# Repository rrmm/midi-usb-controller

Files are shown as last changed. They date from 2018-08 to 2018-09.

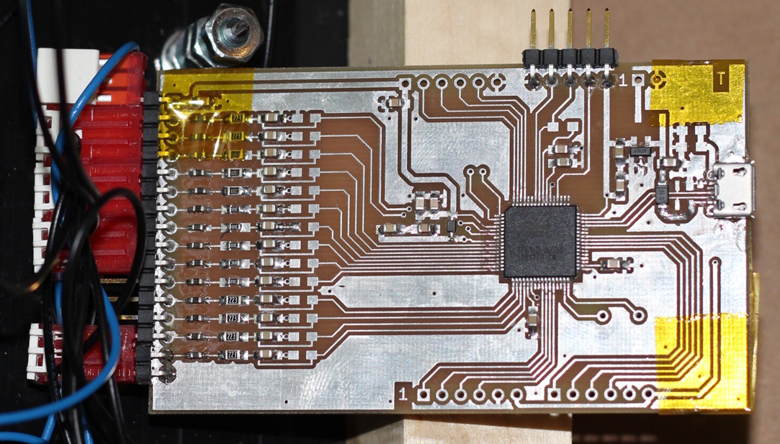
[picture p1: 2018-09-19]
prototype-pcb.jpg

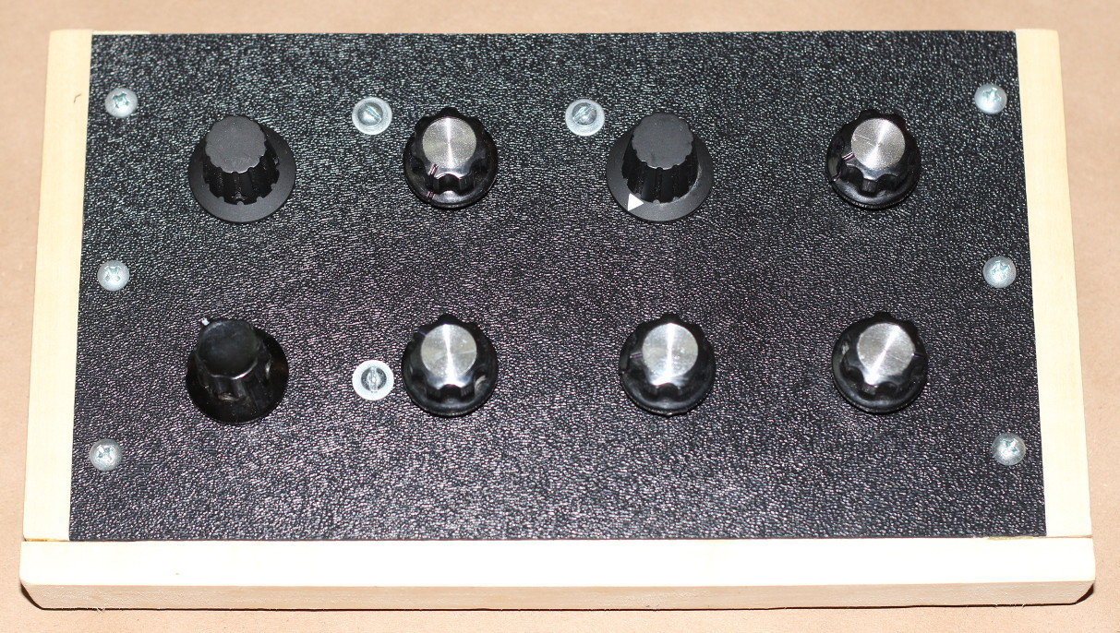
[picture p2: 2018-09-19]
prototype-front.jpg

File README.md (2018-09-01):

# midi-usb-controller

All project files Copyright 2018 RM 
CC BY-SA license with the conditions of the ASF license 

Custom PCB and firmware to implement a MIDI controller board 
- based on Atmel/Microchip ATSAMD21J18A-AU microcontroller
- hardware/gerber contains files necessary to have PCB's manufactured
- USB MIDI device class means no custom drivers are required for WIN or Linux
- bus-powered requires only a single USB micro cable

NOTES
-----
- Controls used were 10K linear potentiometers
- the controls are sampled periodically (~5ms)
- when control changes are detected, they are entered into a FIFO queue
- USB is handled via interrupts and the start of frame (SOF) interrupt checks the queue and transmits 
any events found there
- based on ATMEL STUDIO CDC project with only a single change to the core code to expose one function 
(udd_ep_job_t* udd_ep_get_job(udd_ep_id_t ep))
- several serial ports and crystals are supported by the board to make it more flexible although they are not necessary for 
normal USB operation
- the 100nF capacitors in the low-pass filter of each control input were not used/necessary
- built prototype uses some 10K resistors and some 22K resistors in the low-pass filters without noticible effects
- src/main.c contains the initialization and controller sampling.  It also defines which control is treated as a pitchbend wheel
- src/midi dir contains the actual device implementation and USB config descriptors
- src/config/  contains some important definitions in the clock and usb files (including the midi device descriptor strings)

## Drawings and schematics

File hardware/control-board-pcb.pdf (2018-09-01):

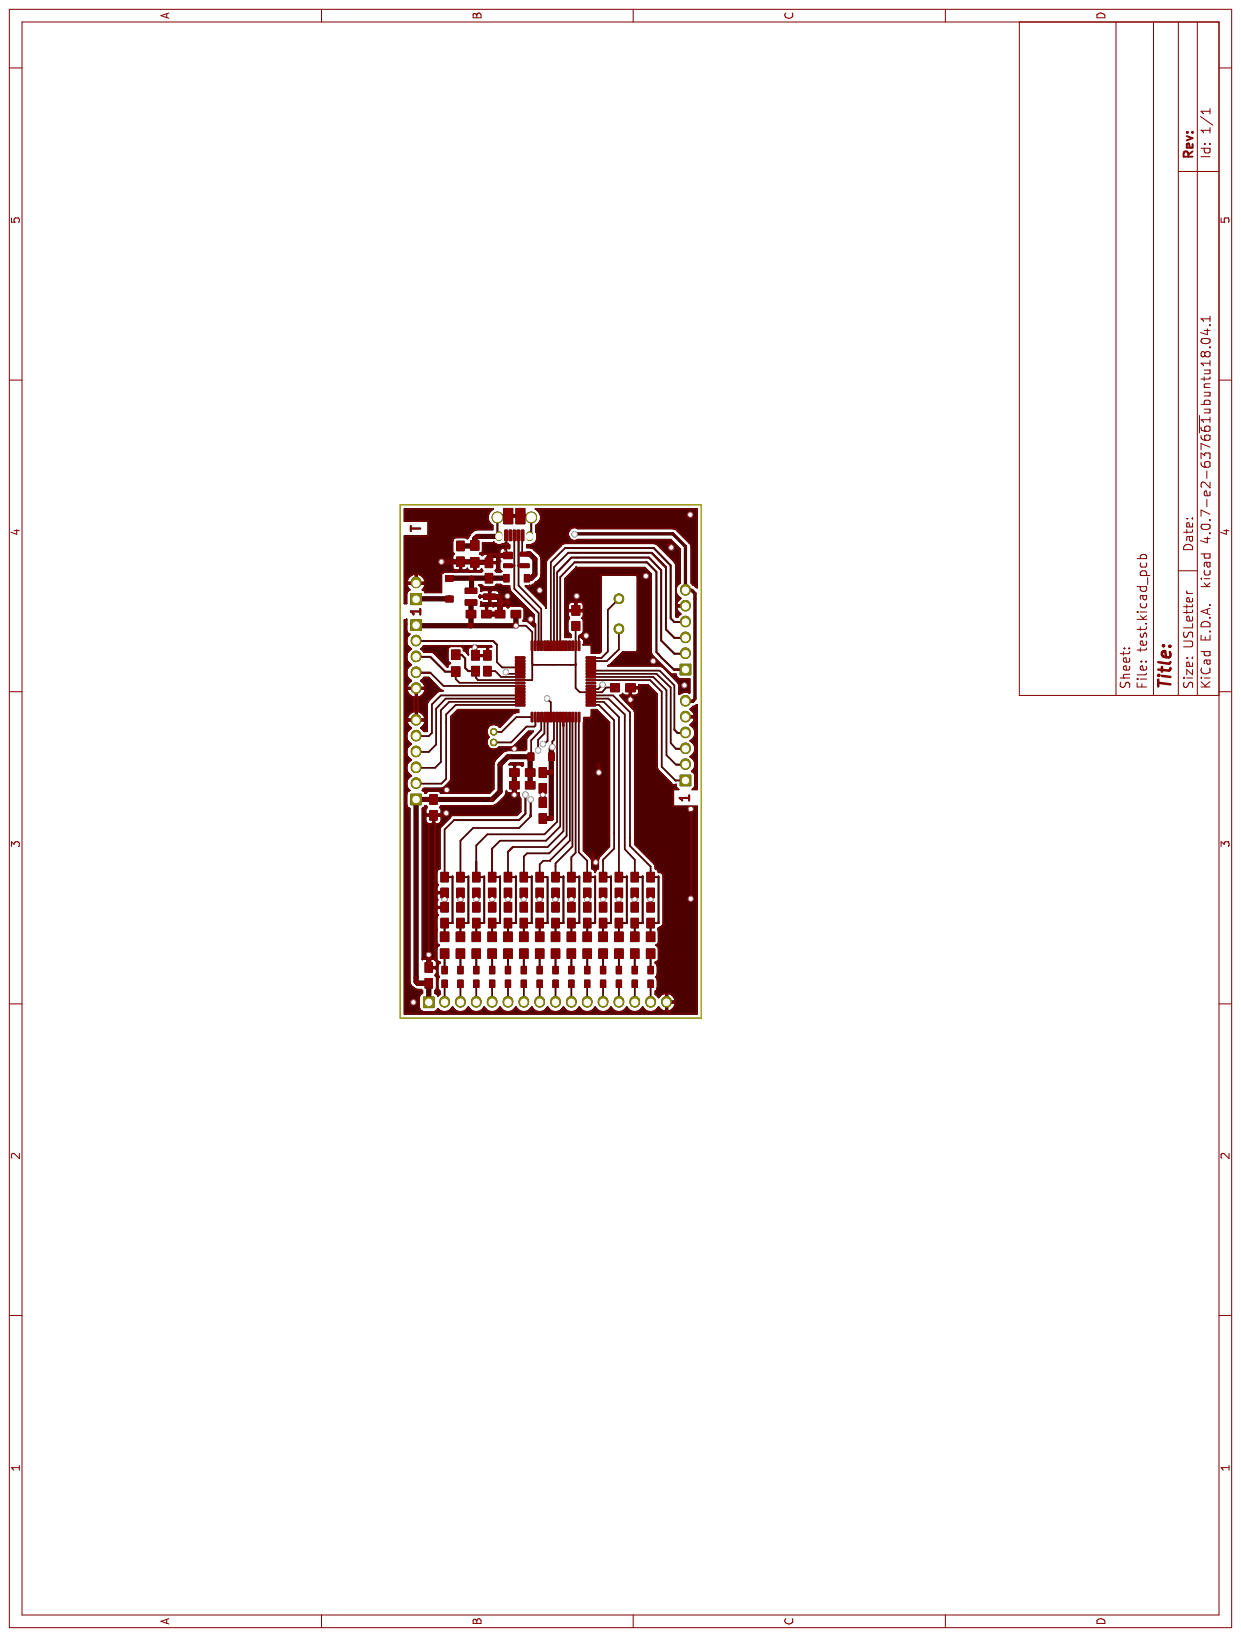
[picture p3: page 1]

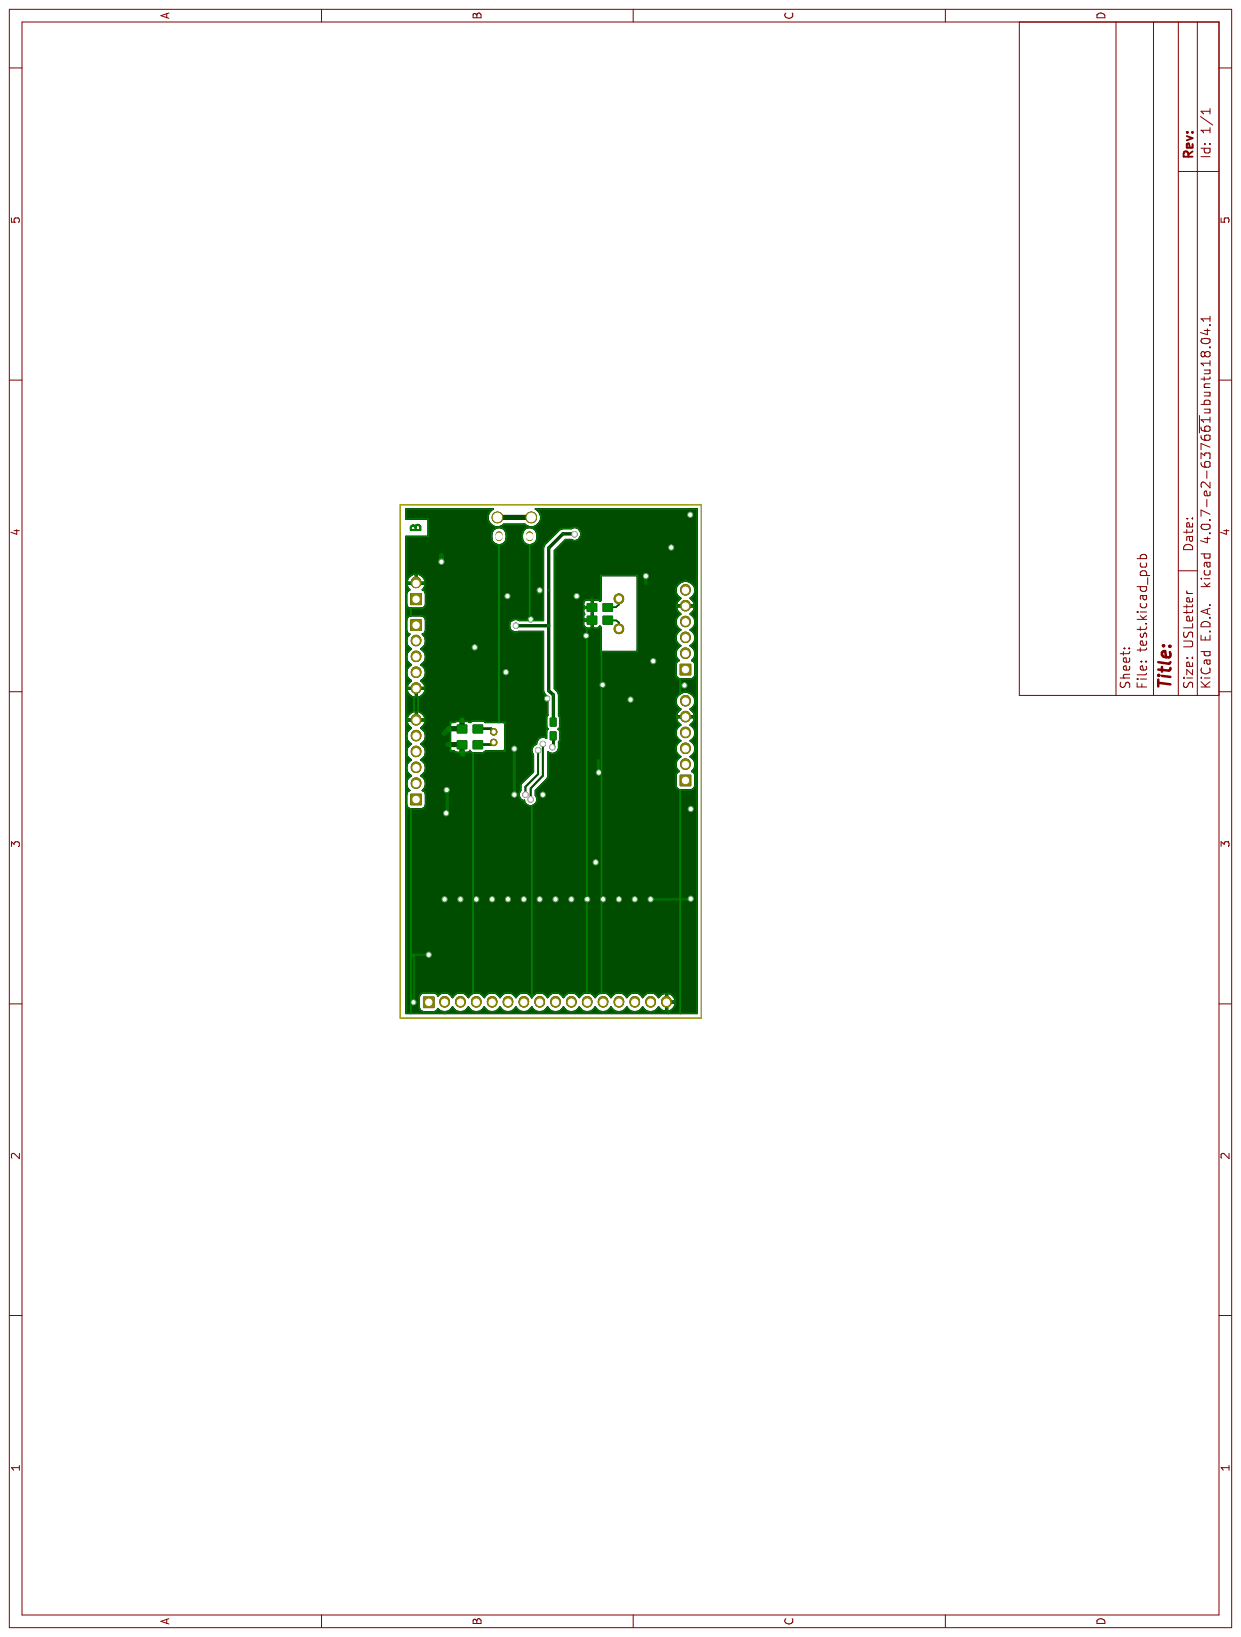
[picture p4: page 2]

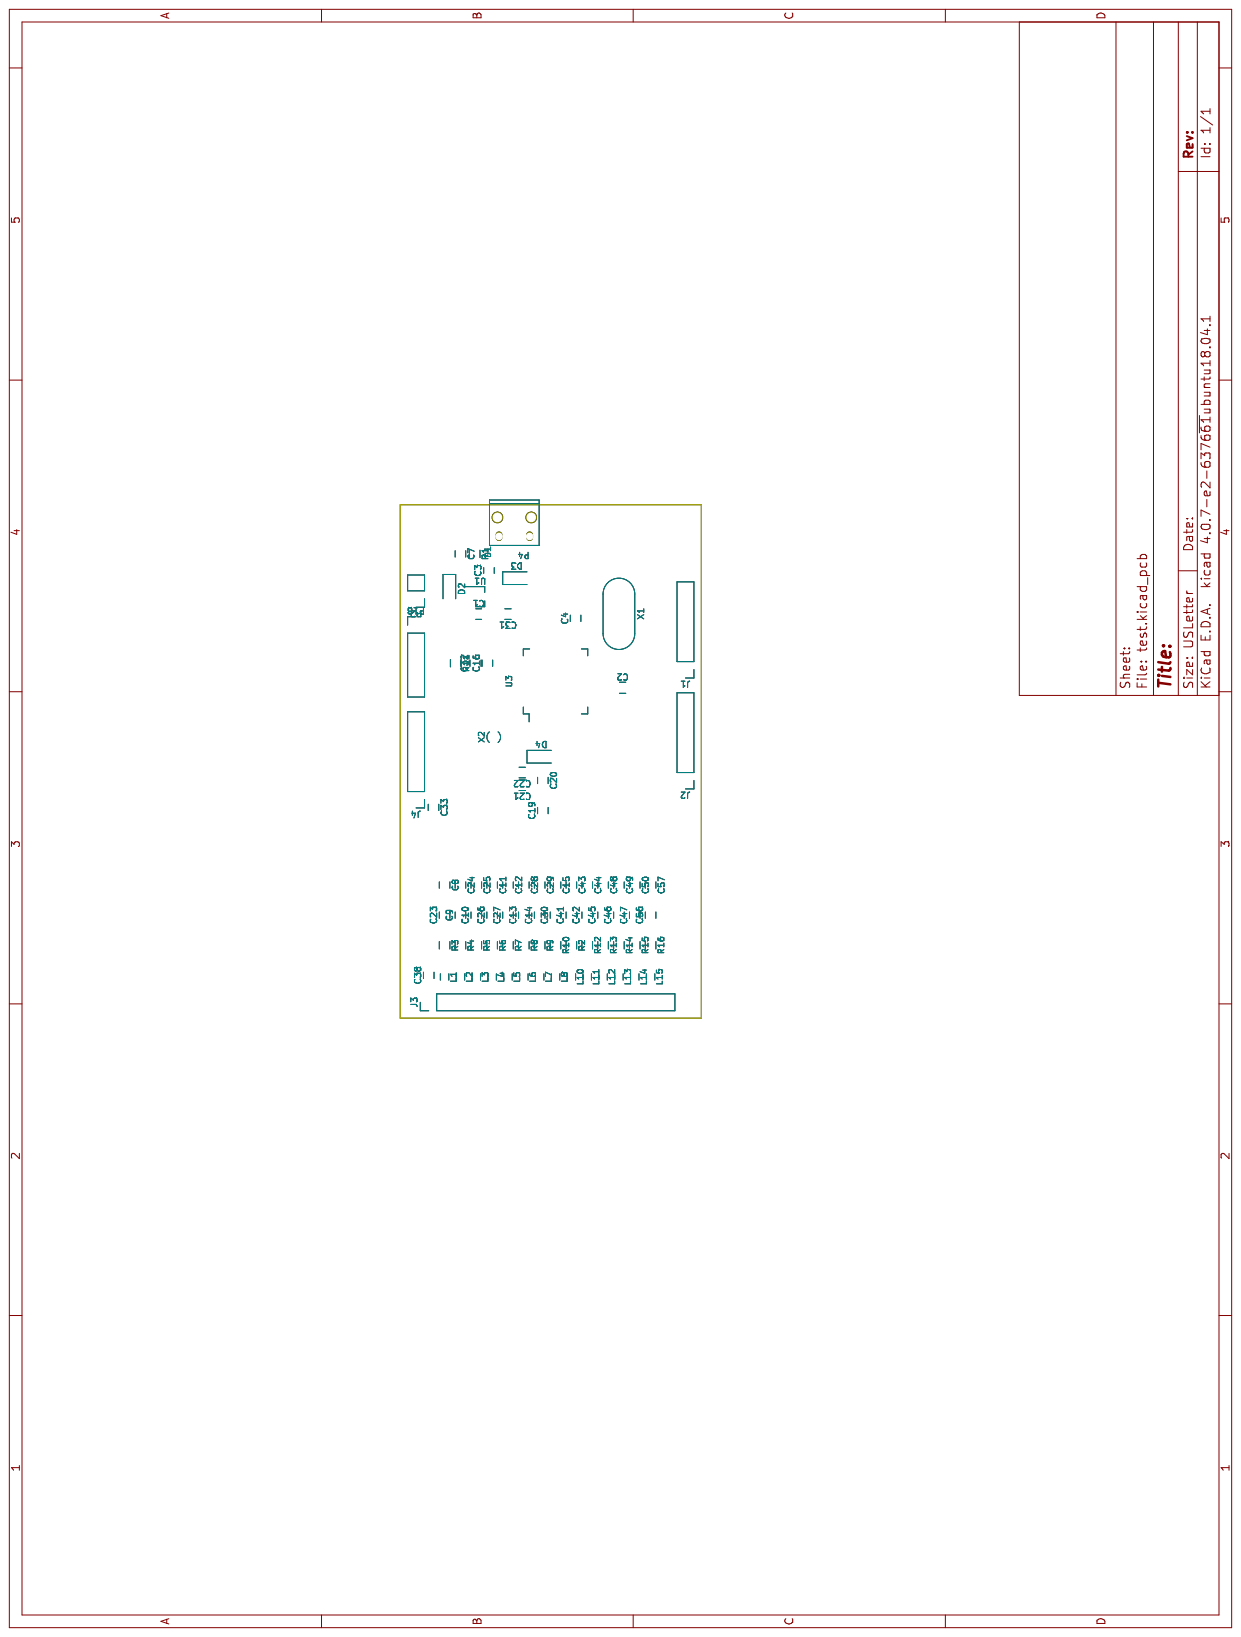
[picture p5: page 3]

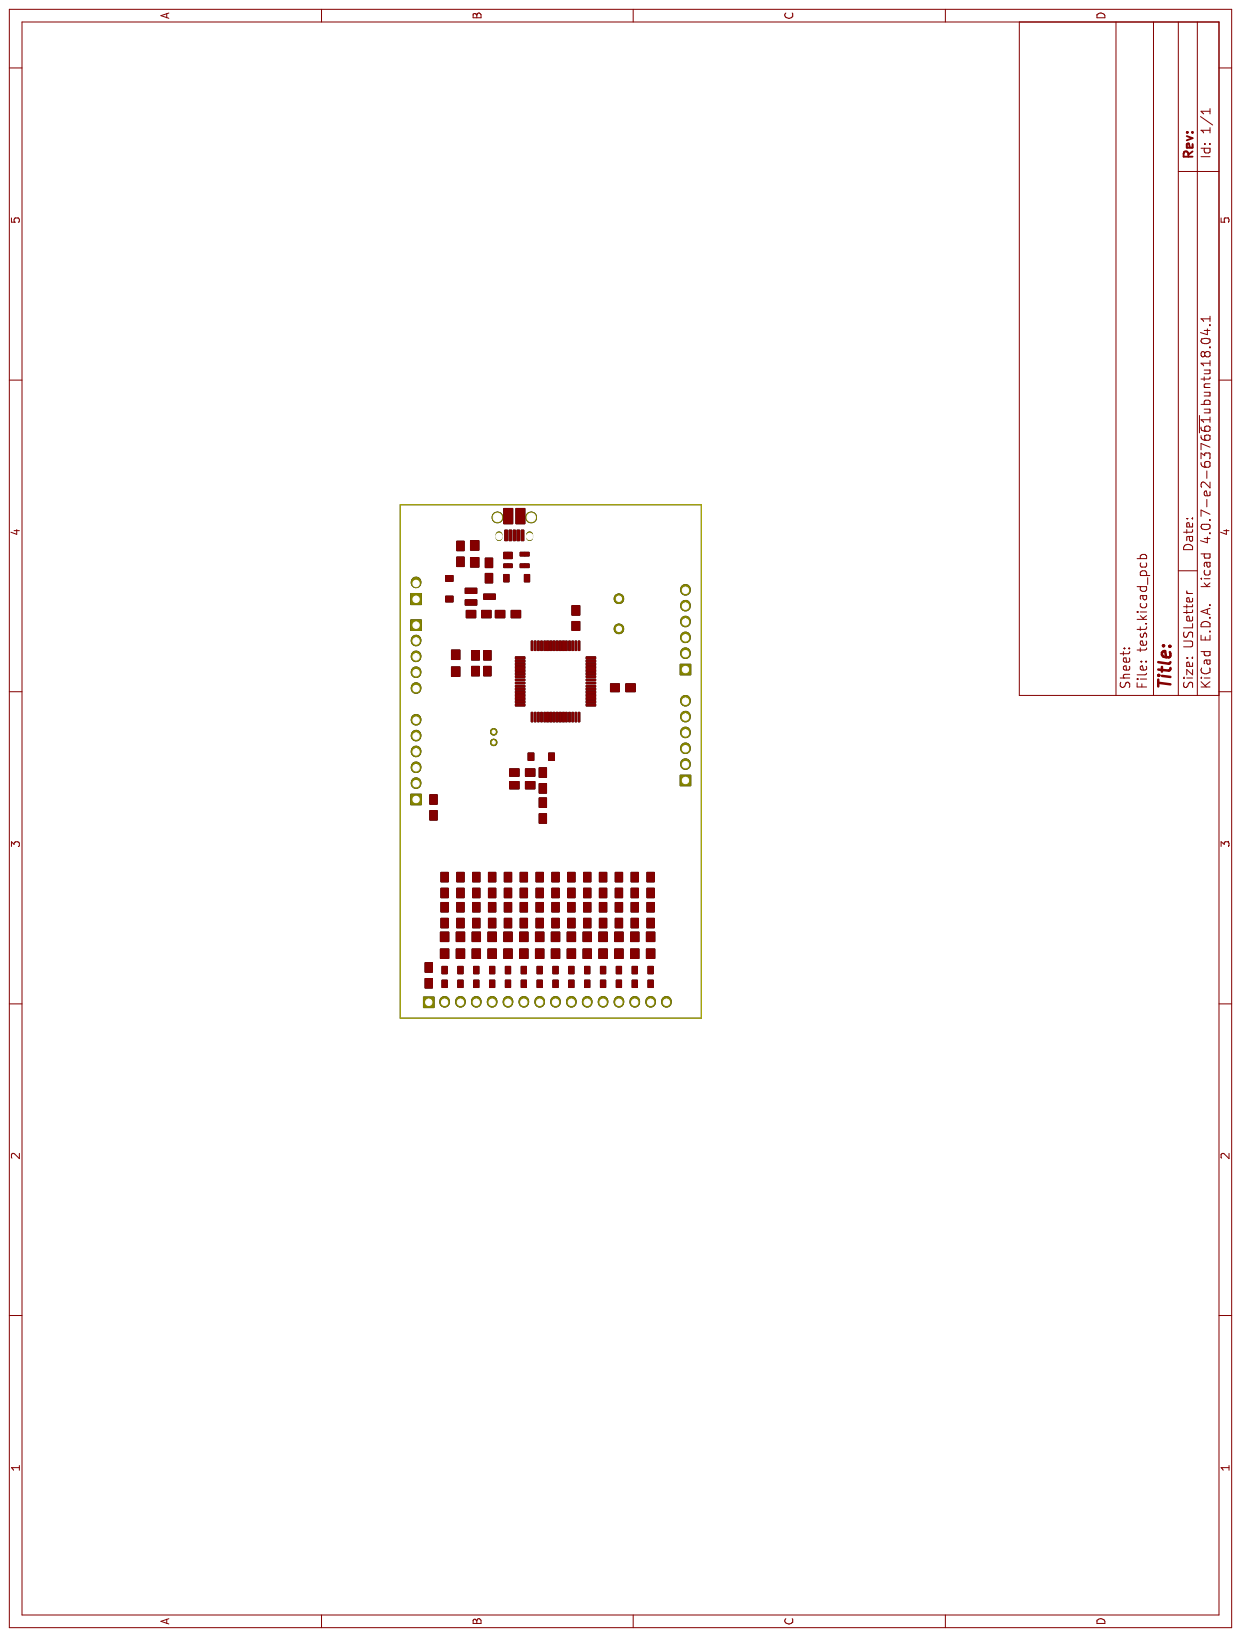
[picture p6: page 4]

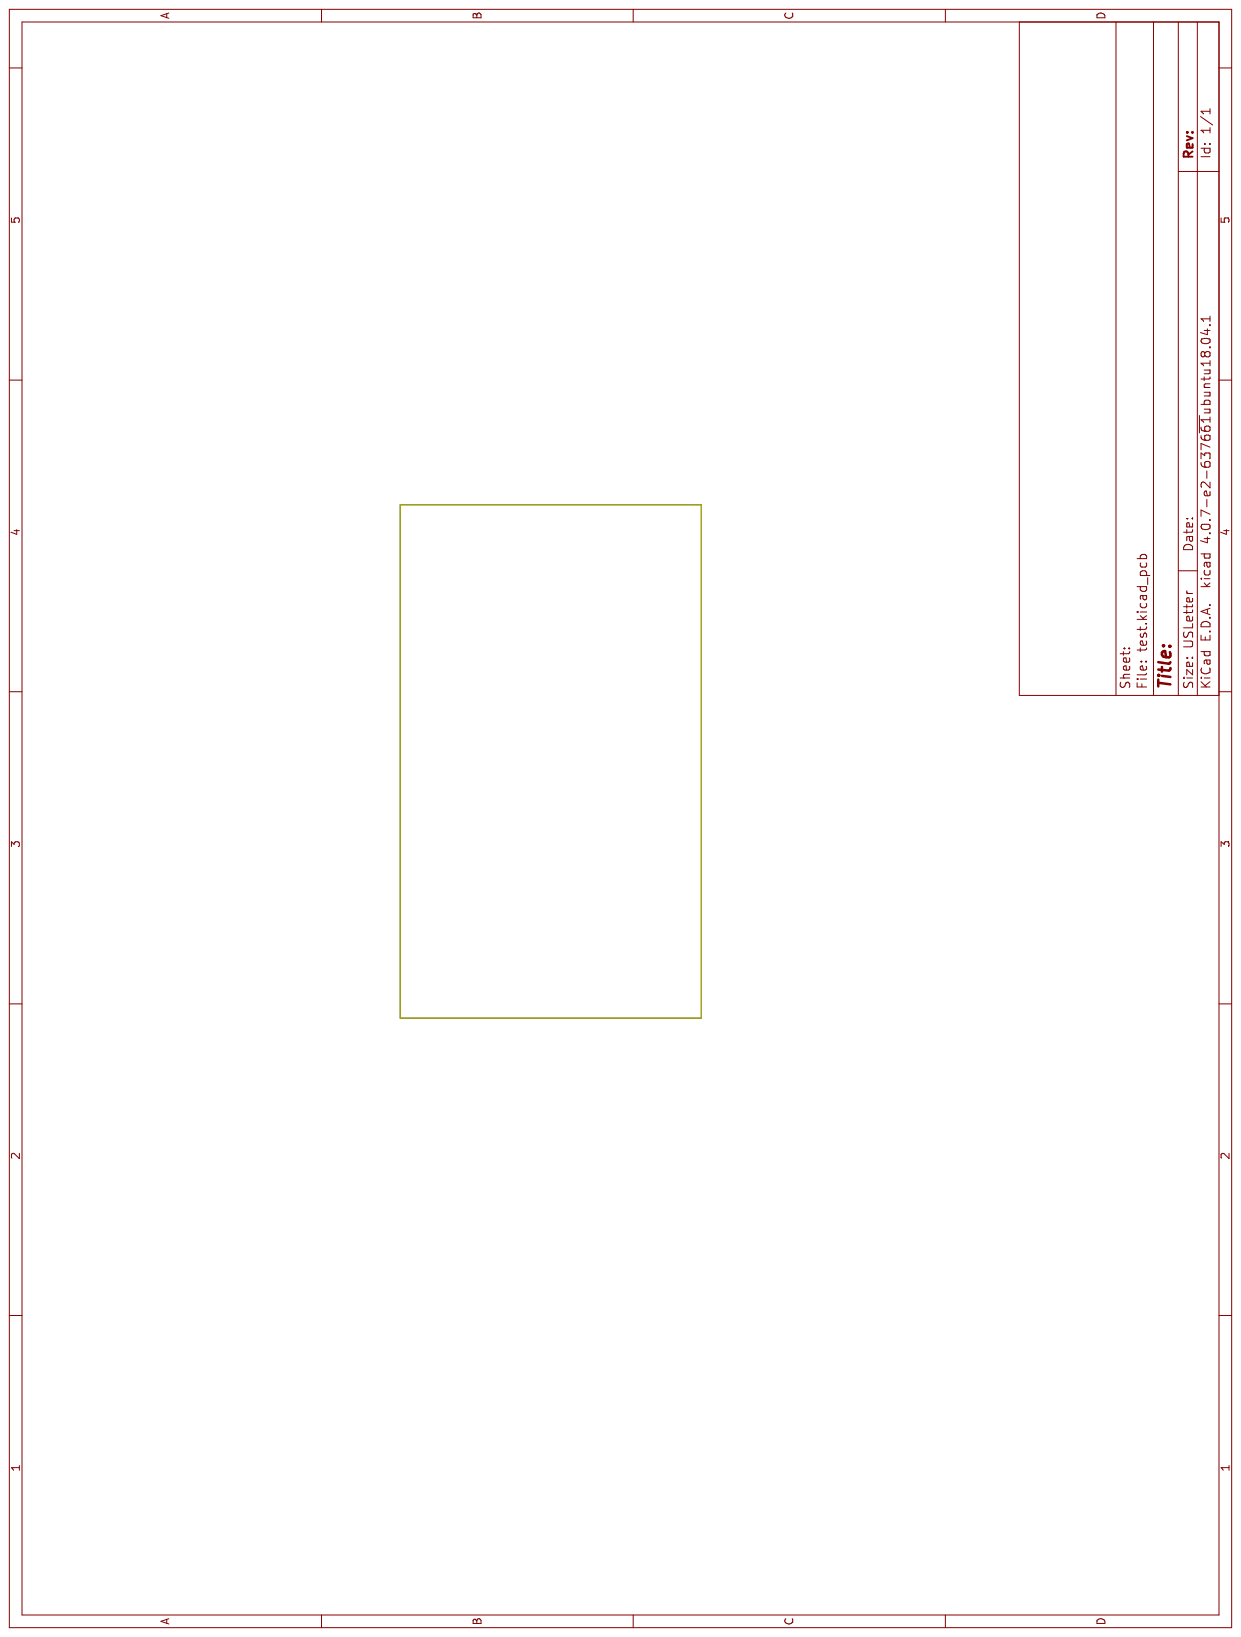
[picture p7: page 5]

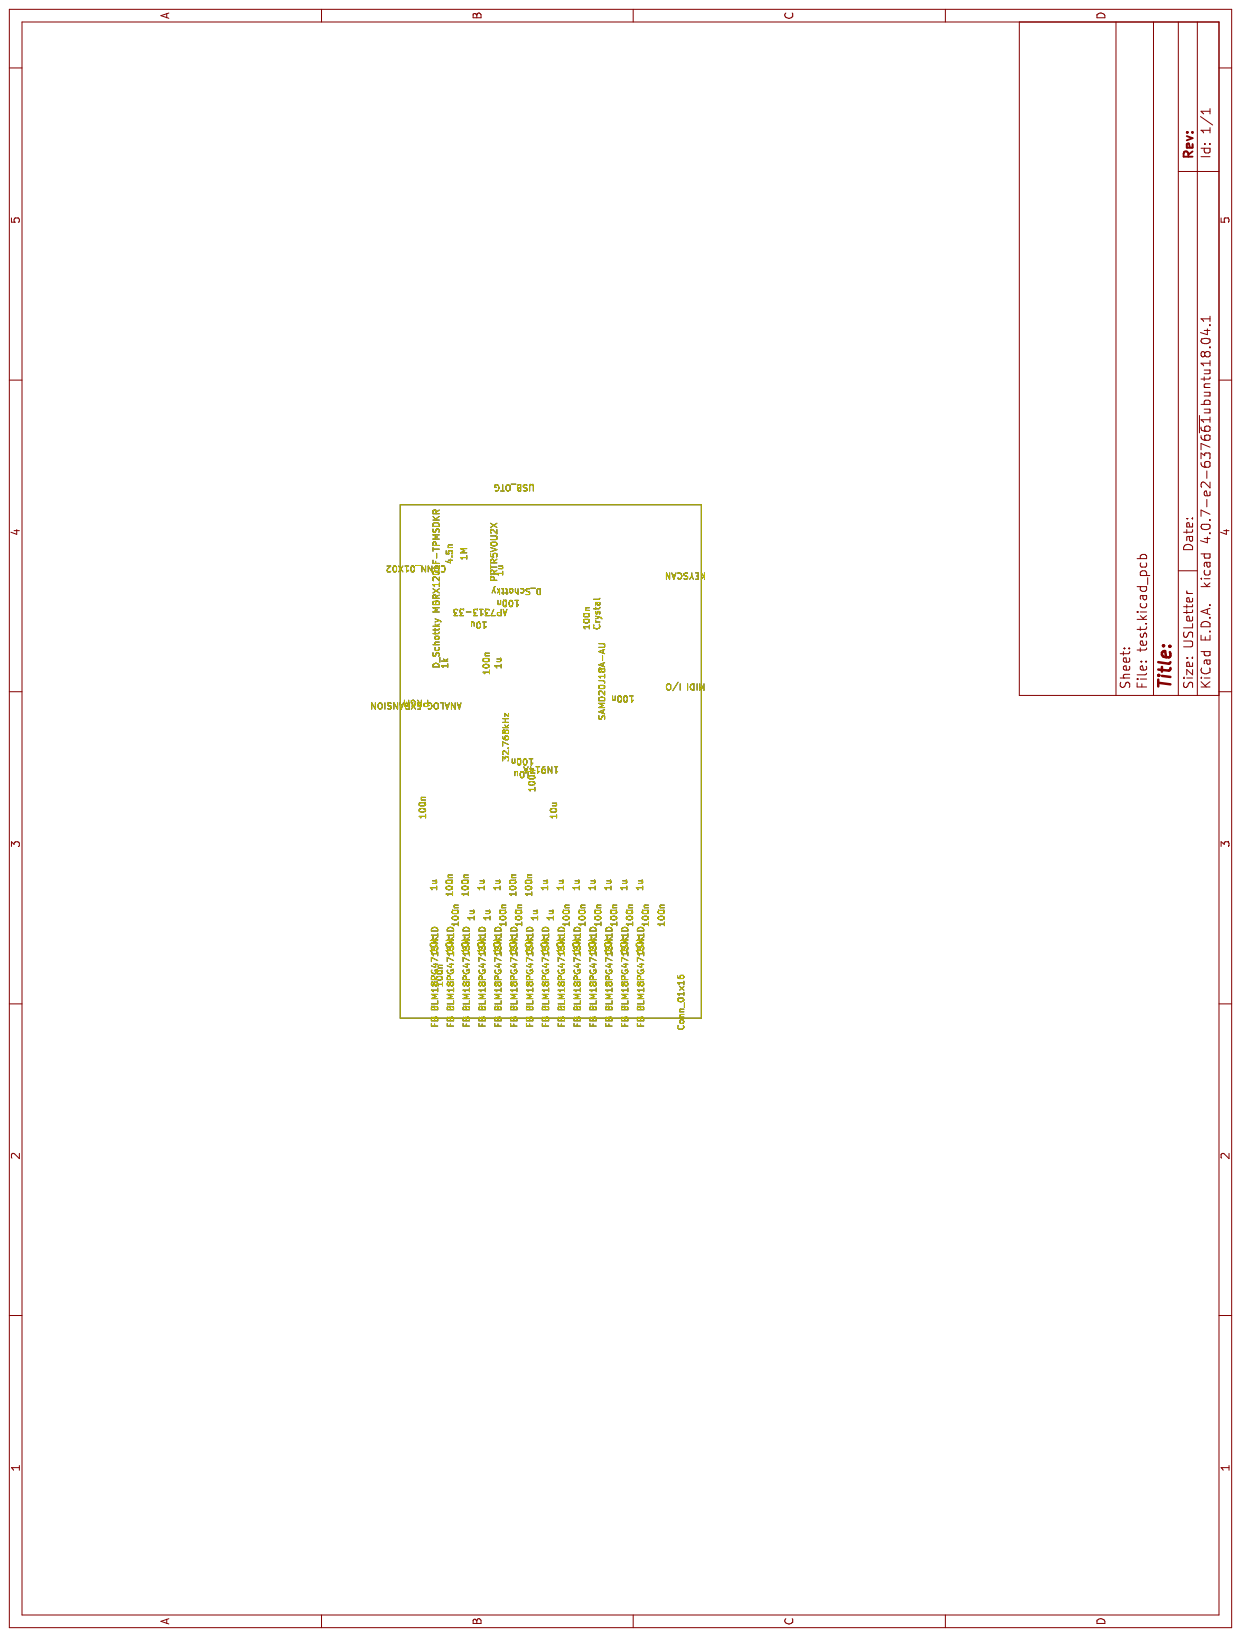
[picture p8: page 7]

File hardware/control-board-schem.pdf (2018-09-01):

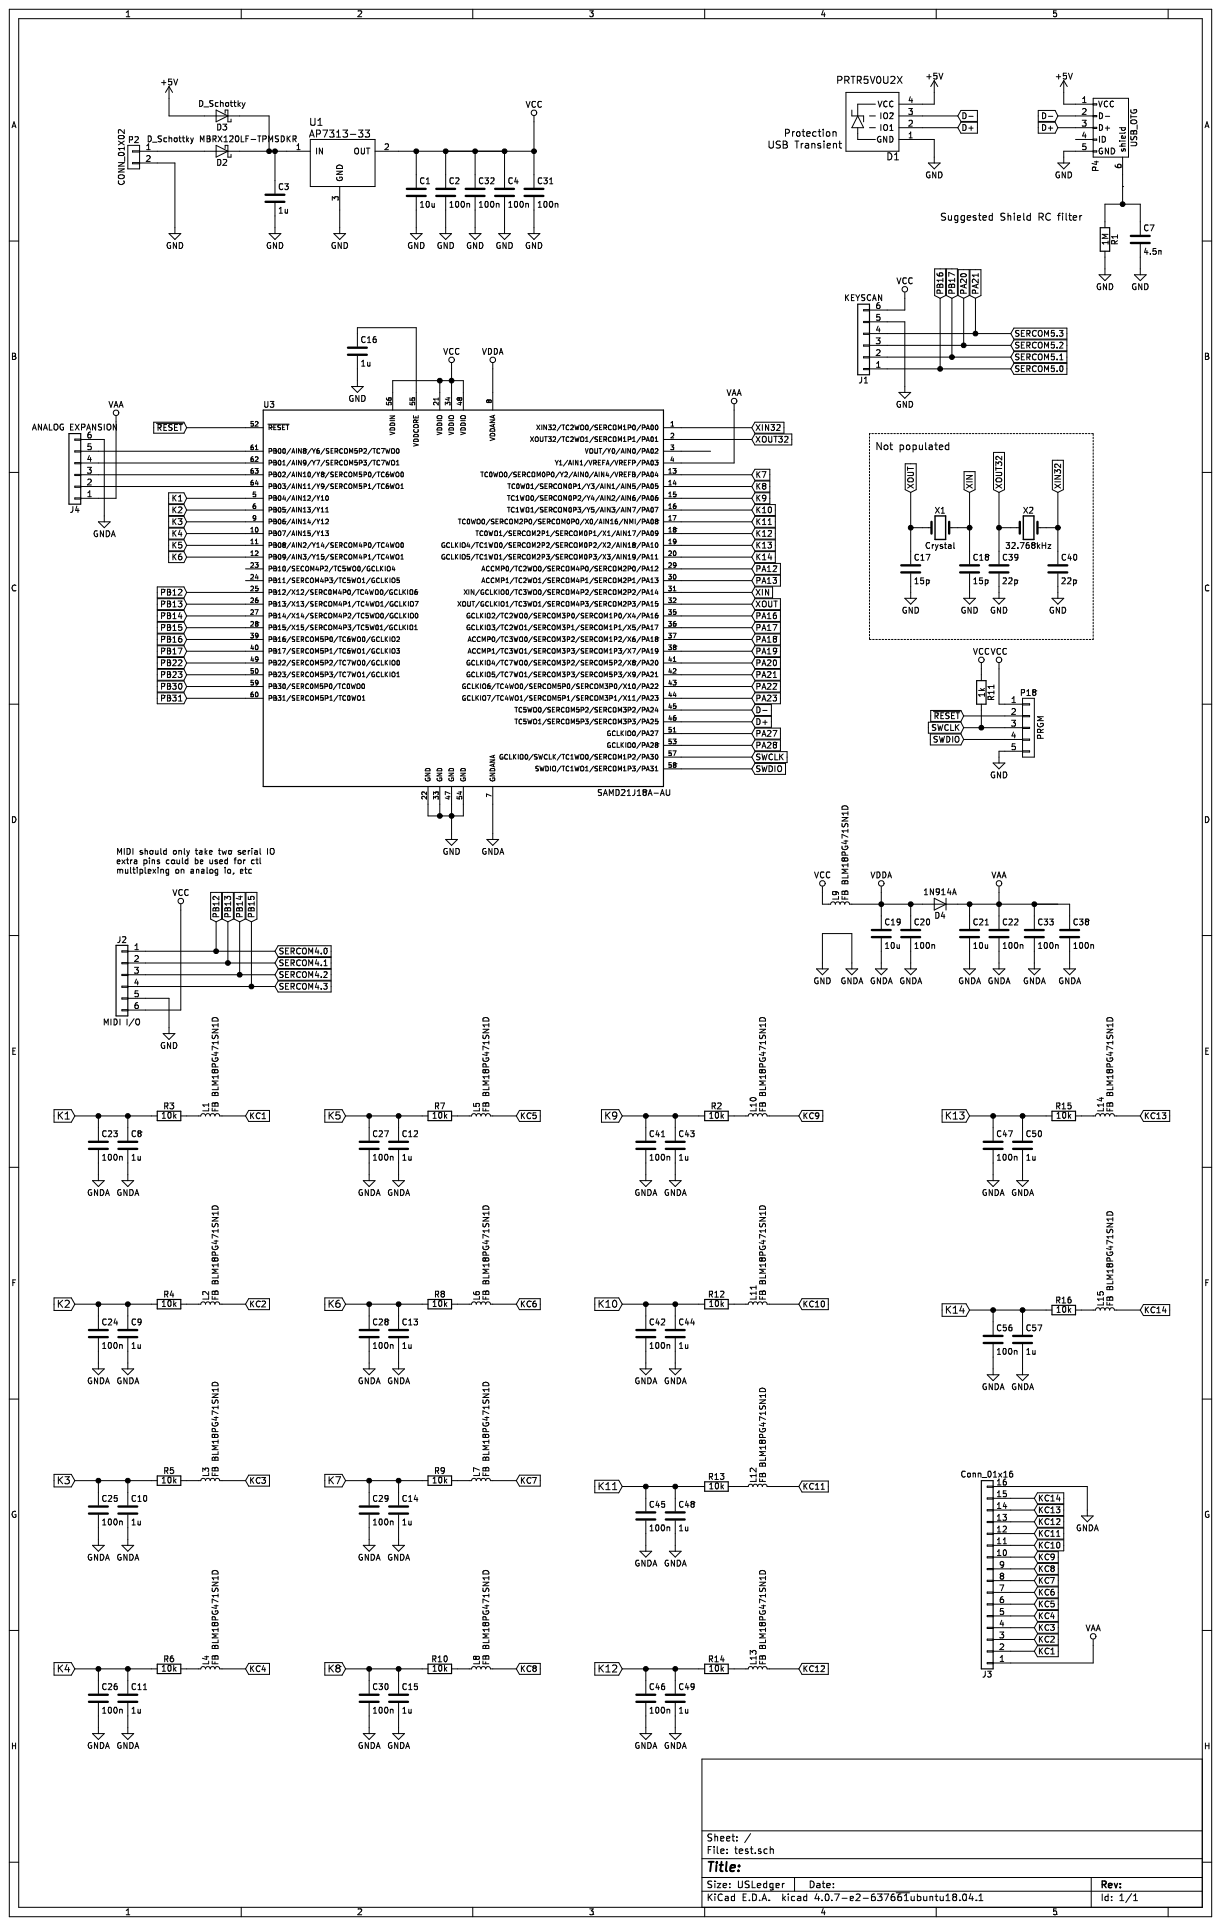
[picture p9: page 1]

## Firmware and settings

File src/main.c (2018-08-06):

// define F_CPU here as the FLL frequency
// otherwise delay_ms(n) functions try to dynamically 
// get the cpu frequency which ends up blowing up the 
// stack and corrupting the 'n' 
#define F_CPU 48000000UL

#include <asf.h>


extern volatile bool DEVICE_ENUMERATED_RUNNING; 
#define N_CTRLS   8

#define PITCHBEND_CTRL_INPUT 0
uint8_t controller_value[N_CTRLS];

struct adc_module adc_instance;

void configure_adc(void);
uint16_t adc_read_value(const uint8_t input_channel);
void scan_controls(bool output_changes);


void
configure_adc(void)
{
  struct adc_config config;
  adc_get_config_defaults(&config);
  config.reference_compensation_enable = false;
  // REF max voltage is VDDANA-.6, // this is pin 20  
  config.reference = ADC_REFERENCE_AREFA;   
  // INTVCC0 is 1/1.48 VDDANA   INTVCC1 is 1/2 VDDANA (but only for VDDANA>2.0)
  //config.reference = ADC_REFERENCE_INTVCC1;  
  // 0-63 ... controls the length of time the sampling is done
  // and controls the input impedence 
  config.sample_length = 63;     
  config.resolution = ADC_RESOLUTION_12BIT;
  config.divide_result = ADC_DIVIDE_RESULT_128;
  config.accumulate_samples = ADC_ACCUMULATE_SAMPLES_128;
  config.pin_scan.inputs_to_scan = 0;
  config.pin_scan.offset_start_scan = 0;
  // clock should be between 30k and 2.1MHz
  config.clock_source = GCLK_GENERATOR_2;  
  
  while (adc_init(&adc_instance, ADC, &config) != STATUS_OK);
  while (adc_enable(&adc_instance) != STATUS_OK);
  
}

// ADC_POSITIVE_INPUT_PIN2 is setup to be the VREFB
uint16_t
adc_read_value(const uint8_t input_channel) {
  enum status_code status;
  enum adc_positive_input input; 
  uint16_t result;
  int retries = 5000;
  
  switch (input_channel) { 
  case 0:
	input = ADC_POSITIVE_INPUT_PIN12;
	break;
  case 1: 
    input = ADC_POSITIVE_INPUT_PIN13;
    break;
  case 2:
    input = ADC_POSITIVE_INPUT_PIN14;
    break;
  case 3:
    input = ADC_POSITIVE_INPUT_PIN15;
    break;
  case 4:
    input = ADC_POSITIVE_INPUT_PIN5;
    break;
  case 5:
    input = ADC_POSITIVE_INPUT_PIN4;
    break; 
  case 6:
    input = ADC_POSITIVE_INPUT_PIN3;
	break; 
  case 7:
    input = ADC_POSITIVE_INPUT_PIN2;
	break;
  case 8:
	input = ADC_POSITIVE_INPUT_PIN15;
    break; 
  case 9:
    input = ADC_POSITIVE_INPUT_PIN9;
	break;
  case 10: 
	input = ADC_POSITIVE_INPUT_PIN10;
	break;
  case 11:
	input = ADC_POSITIVE_INPUT_PIN11;
	break;
  default:
    return 0xffff;
  }
  
  
  adc_set_positive_input(&adc_instance, input);
  adc_start_conversion(&adc_instance);
  do {
    status = adc_read(&adc_instance, &result);
    retries--;
  } while (status == STATUS_BUSY && retries > 0);
  if (status != STATUS_OK) {
    return 0xffff;
  }
  return result;
}




uint16_t current_pitchbend_value = 0x2000;
uint16_t last_sent_pitchbend_value = 0xffff;

// the end points and mid point are of particular interest for the sake of tuning
// so make sure we cover the whole region even though we may not get the adc values
// < 100 or > 16200

inline uint16_t fixup_pitchbend_value(uint16_t value) {
	
	int32_t temp = value; 
	temp -= 8192;    // center around 0
	temp *= 1008; // ideally we want to multiply by ~1.012358648 to scale just slightly bigger use 1012/1000
	temp /= 1000;
	temp += 8192;    // put it back to the normal center

	if (temp < 0) {
		temp = 0;
	} else if (temp > 16383) {
		temp = 16383;
	} else if ((temp > 8192-100) && (temp < 8192+100)) {
		temp = 8192;
	}
	return (uint16_t)temp;
}


inline void handle_pitchbend(bool output_changes, int i, uint16_t value) {
    
    // this is signed so we can deal with the 0 bin appropriately 
	
	//	value = (value>>5)<<7        ;
	value = value << 2; 

	uint16_t fixedup_pitchbend_value = 0;

	bool controller_changed = abs(value - current_pitchbend_value) > 0x1f;


    if (controller_changed) {
		current_pitchbend_value += (value - current_pitchbend_value)/4;
		
	  // we clamp the values and put a deadband in the center
	  // so we might have already sent a 0 or 0x4000 or 0x2000 even though
	  // the raw value changed
	  fixedup_pitchbend_value = fixup_pitchbend_value(current_pitchbend_value);
      if (output_changes && fixedup_pitchbend_value != last_sent_pitchbend_value) {
        // only record the value, if we actually got it in the queue
		if (enqueue_ctrl(CTRL_PITCHBEND, fixedup_pitchbend_value)) {
			last_sent_pitchbend_value = fixedup_pitchbend_value;
		}
      } else {
        //current_pitchbend_value = value;		
      } 
	}
}

// scan the controls, but only send the changes to the midi out if 
// output_changes is true
// we want to apply some hysteresis to the value change so:

// there are 0-127 bins representing each control value
// BIN2RAW converts the bin number to the raw adc value of the middle of a bin
#define HALFBIN_SIZE   (1<<4)
#define GUARD_SIZE     (1<<3)
#define BIN2RAW(x)     (((x)<<5) + HALFBIN_SIZE)


inline void handle_ctrl_value(bool output_changes, int i, uint16_t value) {
    uint8_t res = (value >> 5);  // scale from 0-0x0fff to 0-0x7f
    
    // this is signed so we can deal with the 0 bin appropriately 
    int raw_bin_middle = (int)BIN2RAW(controller_value[i]);
    int raw_bin_high = raw_bin_middle+HALFBIN_SIZE+GUARD_SIZE;
    int raw_bin_low  = raw_bin_middle-HALFBIN_SIZE-GUARD_SIZE;
    bool controller_changed = (value > raw_bin_high) || (value < raw_bin_low);
    
    if (controller_changed) {
      if (output_changes) {
        // only record the value, if we actually got it in the queue
		if (enqueue_ctrl(i, res)) {
			controller_value [i] = res;
		}
      } else {
        controller_value [i] = res;		
      } 
	}
}

void scan_controls(bool output_changes) {
  for (int i = 0; i < N_CTRLS; i++) {
    uint16_t v = adc_read_value(i);
    if (v == 0xffff) {
      continue; // error during adc_read
    }
	if (i == PITCHBEND_CTRL_INPUT) {
		handle_pitchbend(output_changes, i, v);   
	} else {  
		handle_ctrl_value(output_changes, i, v);
	}
  } // for
}


int main (void)
{
  DEVICE_ENUMERATED_RUNNING = false;
  system_init();
  irq_initialize_vectors();
  cpu_irq_enable();
  sleepmgr_init();
  udc_start();
  configure_adc();
  scan_controls(false);

  while (1) {

	while (DEVICE_ENUMERATED_RUNNING) { 
	    scan_controls(true);
		// is this a good tradeoff...we don't want to inundate the
		// host with events
		delay_ms(5);
	}
	sleepmgr_sleep(SLEEPMGR_IDLE_0);
  }
  

}

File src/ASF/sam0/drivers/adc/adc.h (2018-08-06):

/**
 * \file
 *
 * \brief SAM Peripheral Analog-to-Digital Converter Driver
 *
 * Copyright (C) 2012-2016 Atmel Corporation. All rights reserved.
 *
 * \asf_license_start
 *
 * \page License
 *
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
 * 3. The name of Atmel may not be used to endorse or promote products derived
 *    from this software without specific prior written permission.
 *
 * 4. This software may only be redistributed and used in connection with an
 *    Atmel microcontroller product.
 *
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
 * \asf_license_stop
 *
 */
/*
 * Support and FAQ: visit <a href="http://www.atmel.com/design-support/">Atmel Support</a>
 */

#ifndef ADC_H_INCLUDED
#define ADC_H_INCLUDED

/**
 * \defgroup asfdoc_sam0_adc_group SAM Analog-to-Digital Converter (ADC) Driver
 *
 * This driver for Atmel&reg; | SMART ARM&reg;-based microcontrollers provides an interface for the configuration
 * and management of the device's Analog-to-Digital Converter functionality, for
 * the conversion of analog voltages into a corresponding digital form.
 * The following driver Application Programming Interface (API) modes are covered by this manual:
 * - Polled APIs
 * \if ADC_CALLBACK_MODE
 * - Callback APIs
 * \endif
 *
 * The following peripheral is used by this module:
 *  - ADC (Analog-to-Digital Converter)
 *
 * The following devices can use this module:
 * \if DEVICE_SAML21_SUPPORT
 *  - Atmel | SMART SAM L21/L22
 *  - Atmel | SMART SAM C20/C21
 * \else
 *  - Atmel | SMART SAM D20/D21
 *  - Atmel | SMART SAM R21
 *  - Atmel | SMART SAM D09/D10/D11
 *  - Atmel | SMART SAM DA1
 *  - Atmel | SMART SAM HA1
 * \endif
 *
 * The outline of this documentation is as follows:
 *  - \ref asfdoc_sam0_adc_prerequisites
 *  - \ref asfdoc_sam0_adc_module_overview
 *  - \ref asfdoc_sam0_adc_special_considerations
 *  - \ref asfdoc_sam0_adc_extra_info
 *  - \ref asfdoc_sam0_adc_examples
 *  - \ref asfdoc_sam0_adc_api_overview
 *
 *
 * \section asfdoc_sam0_adc_prerequisites Prerequisites
 *
 * There are no prerequisites for this module.
 *
 *
 * \section asfdoc_sam0_adc_module_overview Module Overview
 *
 * This driver provides an interface for the Analog-to-Digital conversion
 * functions on the device, to convert analog voltages to a corresponding
 * digital value. The ADC has up to 12-bit resolution, and is capable of
 * \if DEVICE_SAML21_SUPPORT
 * converting up to 1,000,000 samples per second (MSPS).
 * \else
 * converting up to 500K samples per second (KSPS).
 * \endif
 *
 * The ADC has a compare function for accurate monitoring of user defined
 * thresholds with minimum software intervention required.
 * The ADC may be configured for 8-, 10-, or 12-bit result, reducing the
 * conversion time. ADC conversion results are provided left or right adjusted
 * which eases calculation when the result is represented as a signed integer.
 *
 * The input selection is flexible, and both single-ended and differential
 * measurements can be made. For differential measurements, an optional gain
 * stage is available to increase the dynamic range. In addition, several
 * internal signal inputs are available. The ADC can provide both signed and
 * unsigned results.
 *
 * The ADC measurements can either be started by application software or an
 * incoming event from another peripheral in the device, and both internal and
 * external reference voltages can be selected.
 *
 * \note Internal references will be enabled by the driver, but not disabled.
 *       Any reference not used by the application should be disabled by the application.
 *
 * A simplified block diagram of the ADC can be seen in
 * \ref asfdoc_sam0_adc_module_block_diagram "the figure below".
 *
 * \anchor asfdoc_sam0_adc_module_block_diagram
 * \dot
 * digraph overview {
 * splines = false;
 * rankdir=LR;
 *
 * mux1 [label="Positive input", shape=box];
 * mux2 [label="Negative input", shape=box];
 *
 *
 * mux3 [label="Reference", shape=box];
 *
 * adc [label="ADC", shape=polygon, sides=5, orientation=90, distortion=-0.6, style=filled, fillcolor=darkolivegreen1, height=1, width=1];
 * prescaler [label="PRESCALER", shape=box, style=filled, fillcolor=lightblue];
 *
 * mux1 -> adc;
 * mux2 -> adc;
 * mux3 -> adc:sw;
 * prescaler -> adc;
 *
 * postproc [label="Post processing", shape=box];
 * result [label="RESULT", shape=box, style=filled, fillcolor=lightblue];
 *
 * adc:e -> postproc:w;
 * postproc:e -> result:w;
 *
 * {rank=same; mux1 mux2}
 * {rank=same; prescaler adc}
 *
 * }
 * \enddot
 *
 *
 * \subsection asfdoc_sam0_adc_module_overview_prescaler Sample Clock Prescaler
 * The ADC features a prescaler, which enables conversion at lower clock rates
 * than the input Generic Clock to the ADC module. This feature can be used to
 * lower the synchronization time of the digital interface to the ADC module
 * via a high speed Generic Clock frequency, while still allowing the ADC
 * sampling rate to be reduced.
 *
 * \subsection asfdoc_sam0_adc_module_overview_resolution ADC Resolution
 * The ADC supports full 8-, 10-, or 12-bit resolution. Hardware
 * oversampling and decimation can be used to increase the
 * effective resolution at the expense of throughput. Using oversampling and
 * decimation mode the ADC resolution is increased from 12-bit to an effective
 * 13-, 14-, 15-, or 16-bit. In these modes the conversion rate is reduced, as
 * a greater number of samples is used to achieve the increased resolution. The
 * available resolutions and effective conversion rate is listed in
 * \ref asfdoc_sam0_adc_module_conversion_rate "the table below".
 *
 * \anchor asfdoc_sam0_adc_module_conversion_rate
 * <table>
 *	<caption>Effective ADC Conversion Speed Using Oversampling</caption>
 *	<tr>
 *		<th>Resolution</th>
 *		<th>Effective conversion rate</th>
 *	</tr>
 *	<tr>
 *		<td>13-bit</td>
 *		<td>Conversion rate divided by 4</td>
 *	</tr>
 *	<tr>
 *		<td>14-bit</td>
 *		<td>Conversion rate divided by 16</td>
 *	</tr>
 *	<tr>
 *		<td>15-bit</td>
 *		<td>Conversion rate divided by 64</td>
 *	</tr>
 *	<tr>
 *		<td>16-bit</td>
 *		<td>Conversion rate divided by 256</td>
 *	</tr>
 * </table>
 *
 * \subsection asfdoc_sam0_adc_module_overview_conversion Conversion Modes
 * ADC conversions can be software triggered on demand by the user application,
 * if continuous sampling is not required. It is also possible to configure the
 * ADC in free running mode, where new conversions are started as soon as the
 * previous conversion is completed, or configure the ADC to scan across a
 * number of input pins (see \ref asfdoc_sam0_adc_module_overview_pin_scan).
 *
 * \subsection asfdoc_sam0_adc_module_overview_diff_mode Differential and Single-ended Conversion
 * The ADC has two conversion modes; differential and single-ended. When
 * measuring signals where the positive input pin is always at a higher voltage
 * than the negative input pin, the single-ended conversion mode should be used
 * in order to achieve a full 12-bit output resolution.
 *
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

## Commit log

2018-09-01 added hardware schematics and gerbers
    [cbsc-B.Cu.gbr, cbsc-Edge.Cuts.gbr, cbsc-F.Cu.gbr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]
2018-09-19 added some pics of prototype controller and pcb
